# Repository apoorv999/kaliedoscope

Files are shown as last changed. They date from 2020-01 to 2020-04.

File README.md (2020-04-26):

# Kaliedoscope
This project is arduino based Kaliedoscope, developed at CEDT, NSUT. It comprises of two layers of boards. Top layer contains 4 RGB LEDs, switch, USB port for charging and connector for lipo battery. The  lower layer consists of Arduino nano, tilt sensors and power on LED. In this repository you can find the schematic and board files of these layers of boards and also the code for arduino (.ino) for this project.
## Images
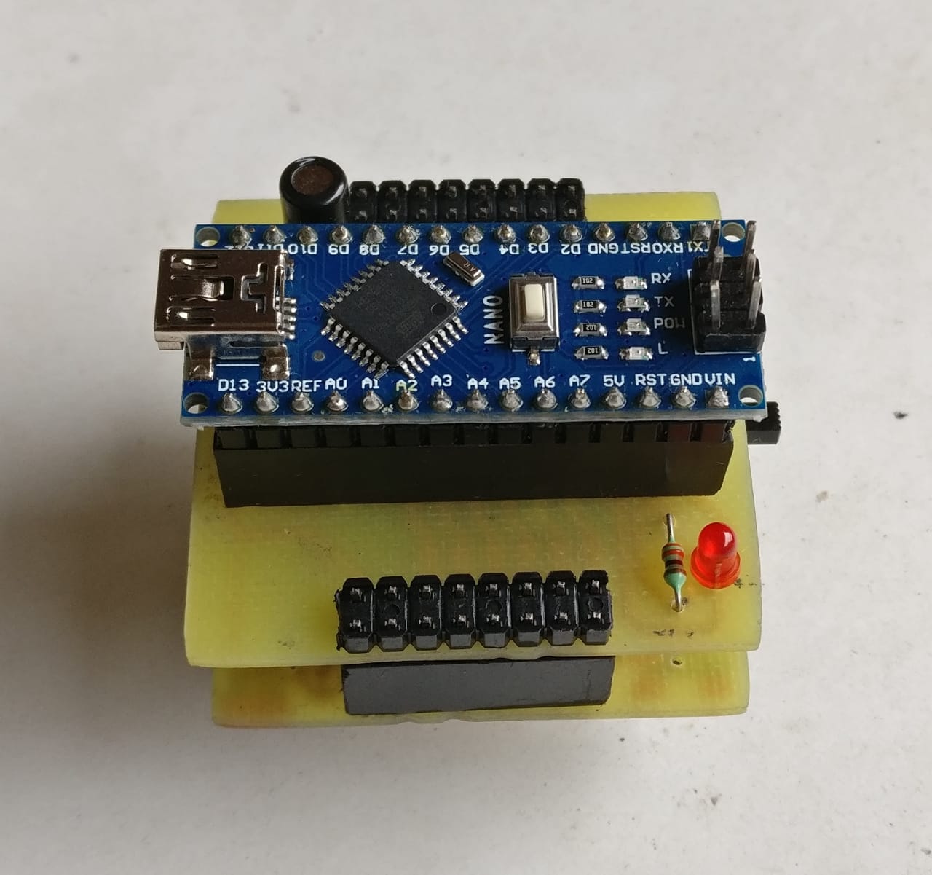
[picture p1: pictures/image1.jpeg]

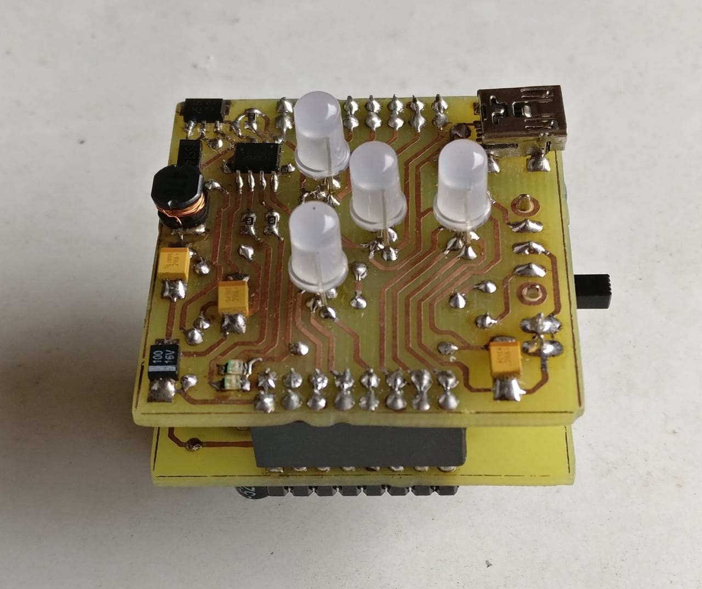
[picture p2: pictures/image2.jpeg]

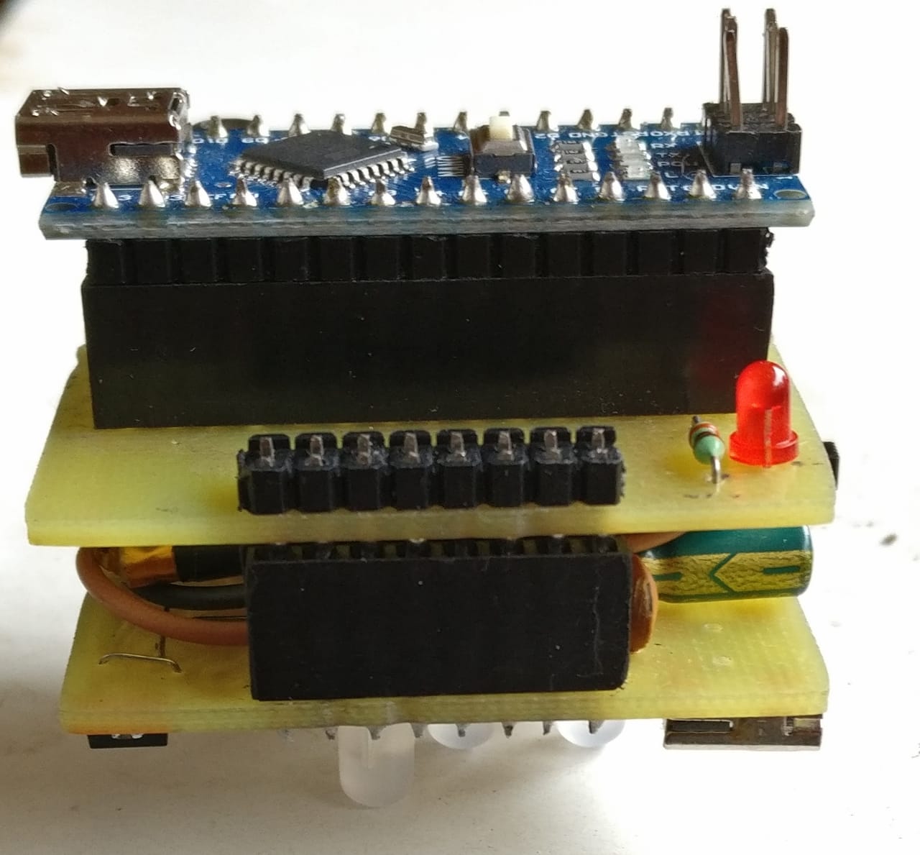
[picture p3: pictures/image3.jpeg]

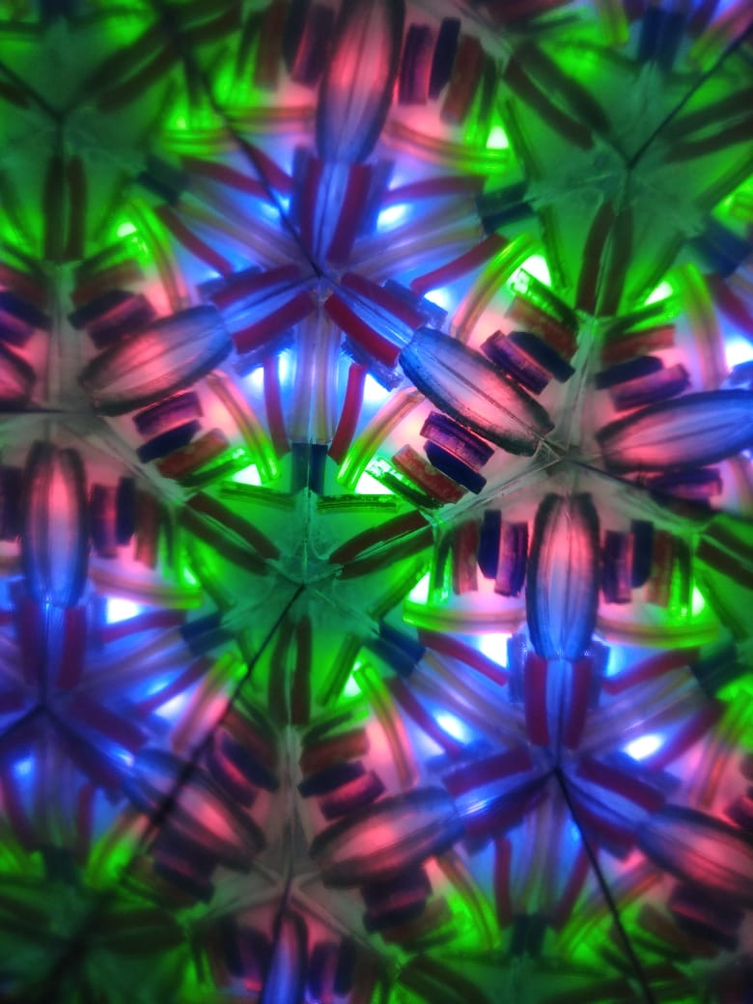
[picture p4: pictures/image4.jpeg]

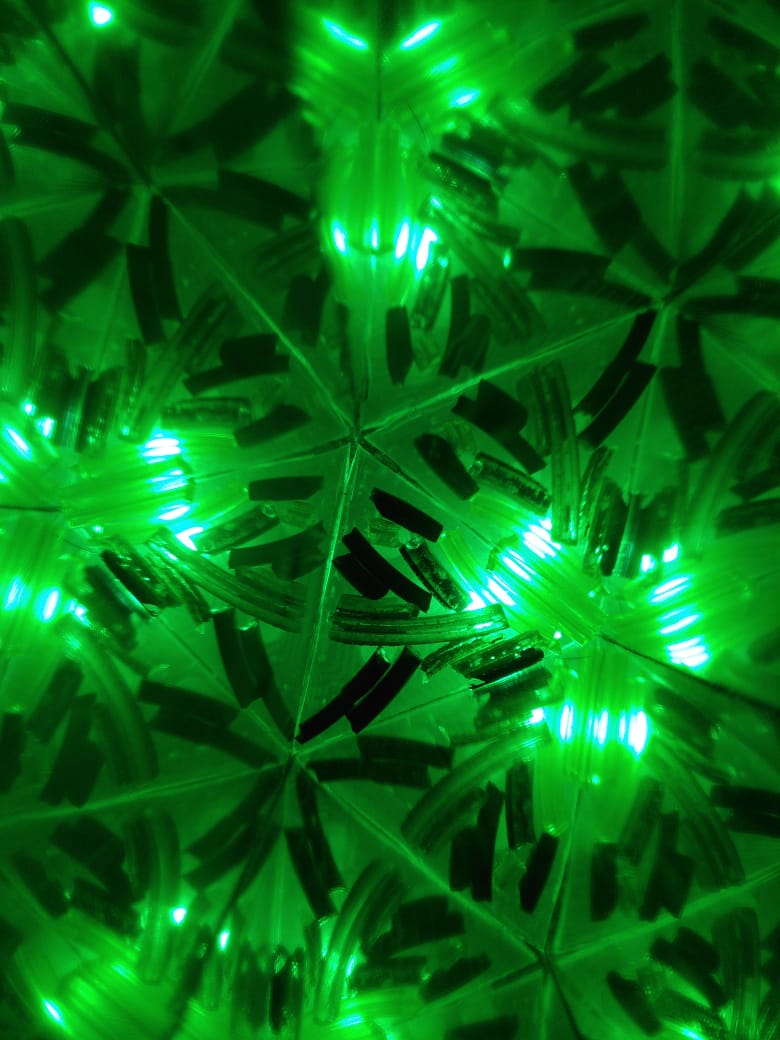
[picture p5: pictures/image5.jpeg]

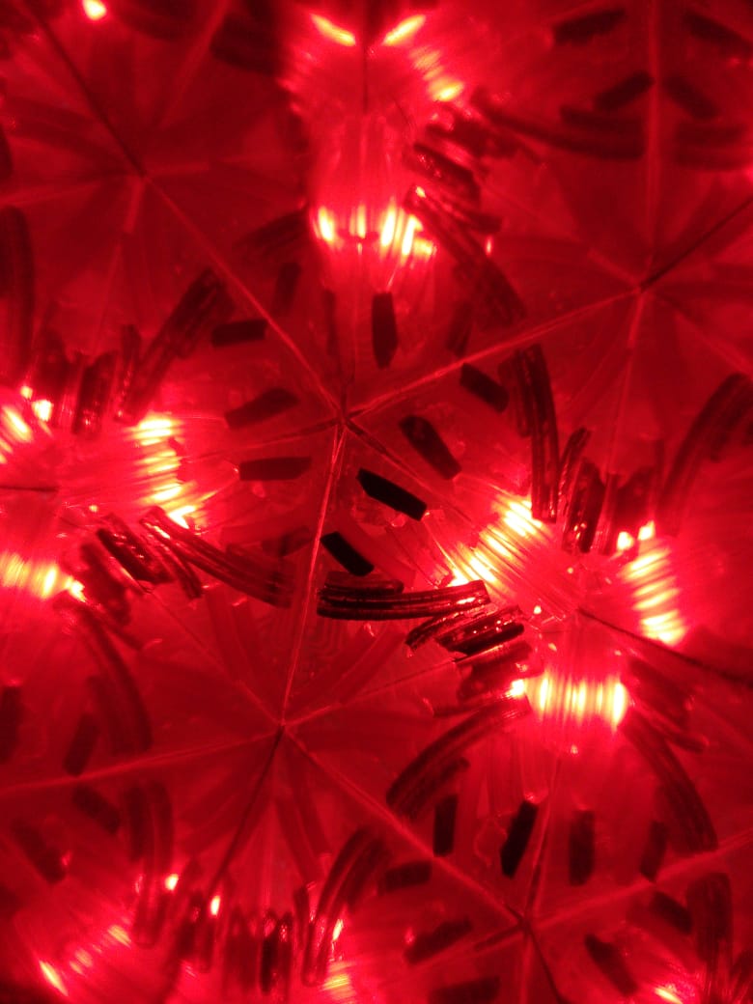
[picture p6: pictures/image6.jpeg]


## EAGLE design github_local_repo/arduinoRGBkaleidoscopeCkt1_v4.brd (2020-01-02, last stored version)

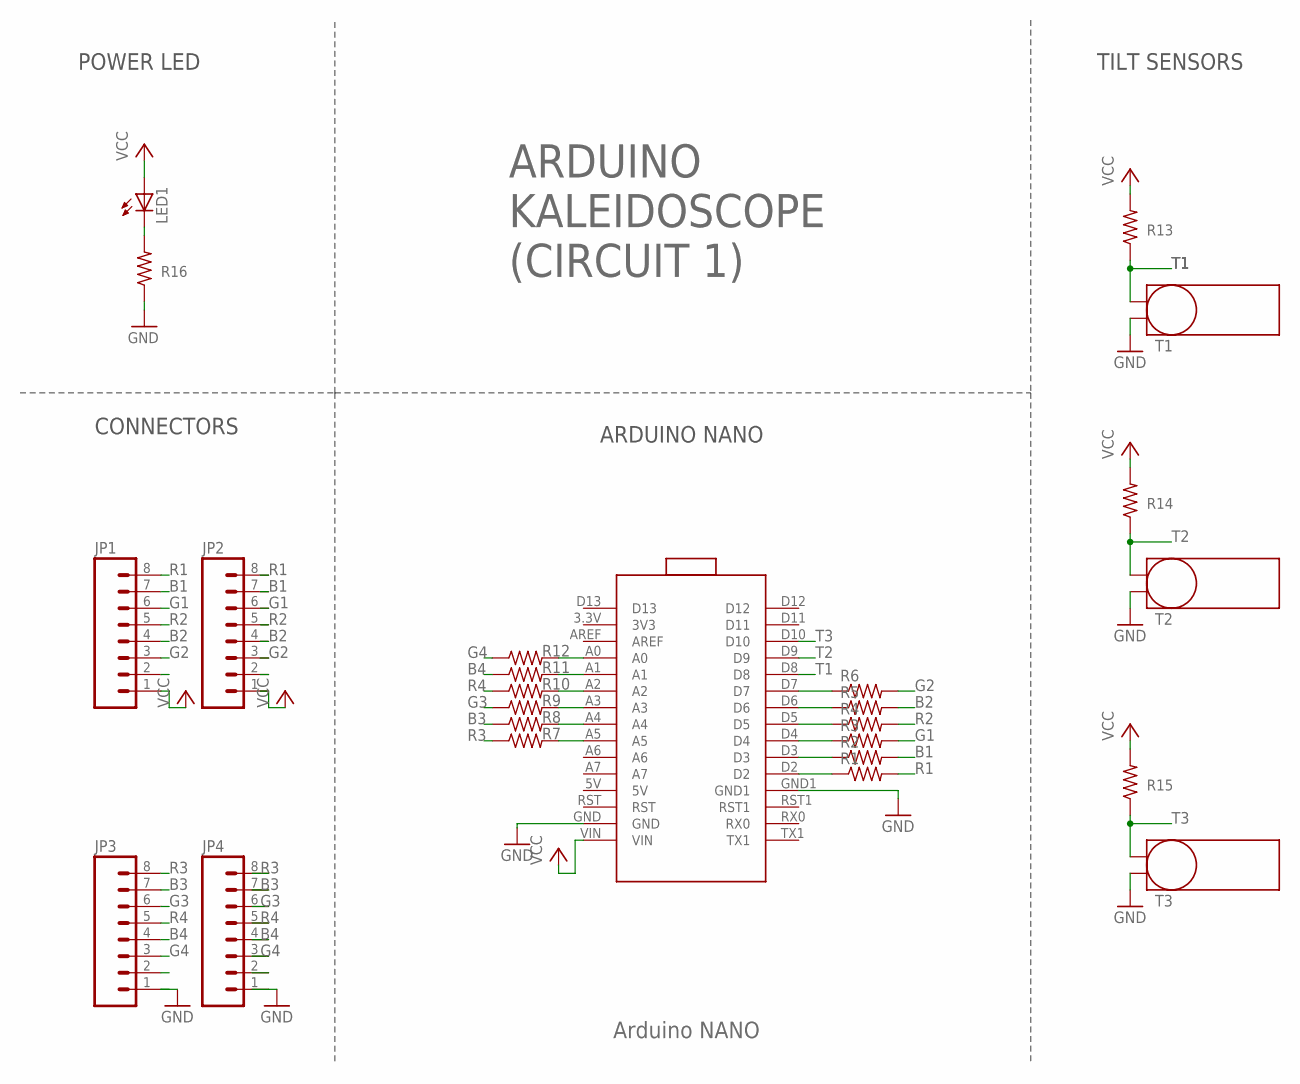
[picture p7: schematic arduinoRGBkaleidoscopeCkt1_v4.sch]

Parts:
JP1, JP2, JP3, JP4: M081X08; 1X08
LED1: LED3MM
R1, R2, R3, R4, R5, R6, R7, R8, R9, R10, R11, R12: RESISTOR0805; R0805
R13, R14, R15, R16: R-US_0204/7; 0204/7
T1, T2, T3: TILTSENSORE2.5-7; TILTSENSOR
U$2: NANO; NANO-2

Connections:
B1: JP1.7, JP2.7, R2.2
B2: JP1.4, JP2.4, R5.2
B3: JP3.7, JP4.7, R8.1
B4: JP3.4, JP4.4, R11.1
G1: JP1.6, JP2.6, R3.2
G2: JP1.3, JP2.3, R6.2
G3: JP3.6, JP4.6, R9.1
G4: JP3.3, JP4.3, R12.1
GND: JP3.1, JP4.1, R16.1, T1.-, T2.-, T3.-, U$2.GND, U$2.GND1
unnamed: R12.2, U$2.A0
unnamed: R11.2, U$2.A1
unnamed: R10.2, U$2.A2
unnamed: R9.2, U$2.A3
unnamed: R8.2, U$2.A4
unnamed: R7.2, U$2.A5
unnamed: R6.1, U$2.D7
unnamed: R5.1, U$2.D6
unnamed: R4.1, U$2.D5
unnamed: R3.1, U$2.D4
unnamed: R2.1, U$2.D3
unnamed: R1.1, U$2.D2
unnamed: LED1.K (C), R16.2
R1: JP1.8, JP2.8, R1.2
R2: JP1.5, JP2.5, R4.2
R3: JP3.8, JP4.8, R7.1
R4: JP3.5, JP4.5, R10.1
T1: R13.1, T1.+, U$2.D8
T2: R14.1, T2.+, U$2.D9
T3: R15.1, T3.+, U$2.D10
VCC: JP1.1, JP2.1, LED1.A, R13.2, R14.2, R15.2, U$2.VIN

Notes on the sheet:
Arduino NANO
POWER LED
TILT SENSORS
ARDUINO NANO
CONNECTORS
ARDUINO KALEIDOSCOPE (CIRCUIT 1)

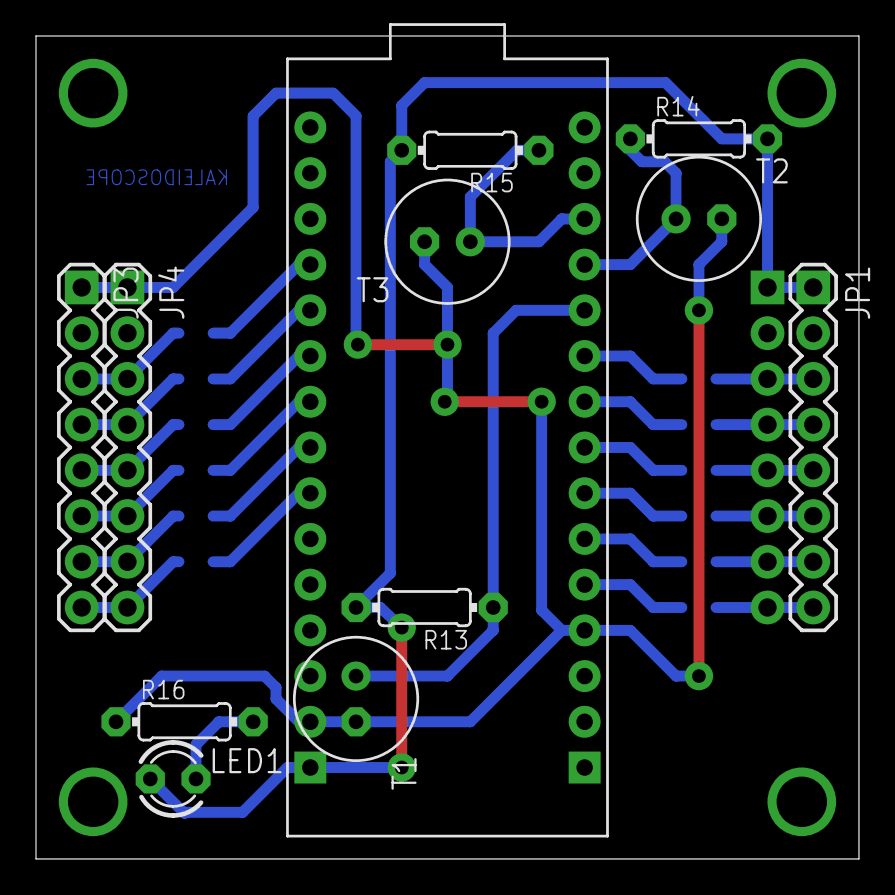
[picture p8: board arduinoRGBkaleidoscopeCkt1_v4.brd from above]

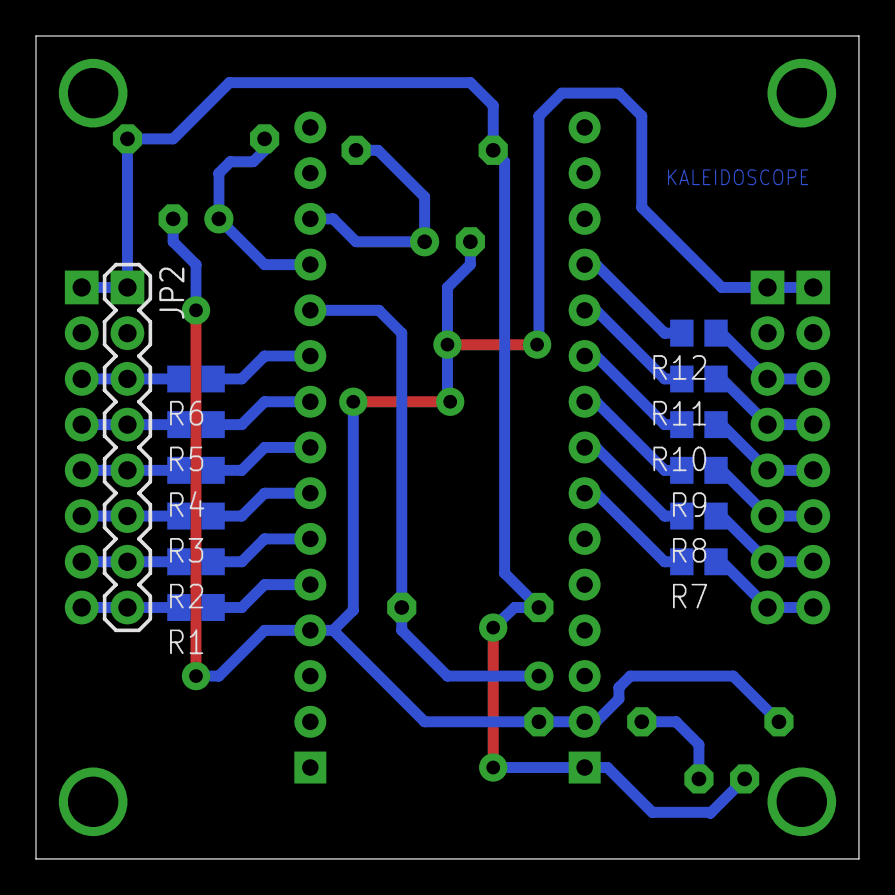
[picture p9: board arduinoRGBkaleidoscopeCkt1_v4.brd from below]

Board: 2 copper layers, 45.7 x 45.7 mm, 25 parts (13 on the bottom side), 30 nets.

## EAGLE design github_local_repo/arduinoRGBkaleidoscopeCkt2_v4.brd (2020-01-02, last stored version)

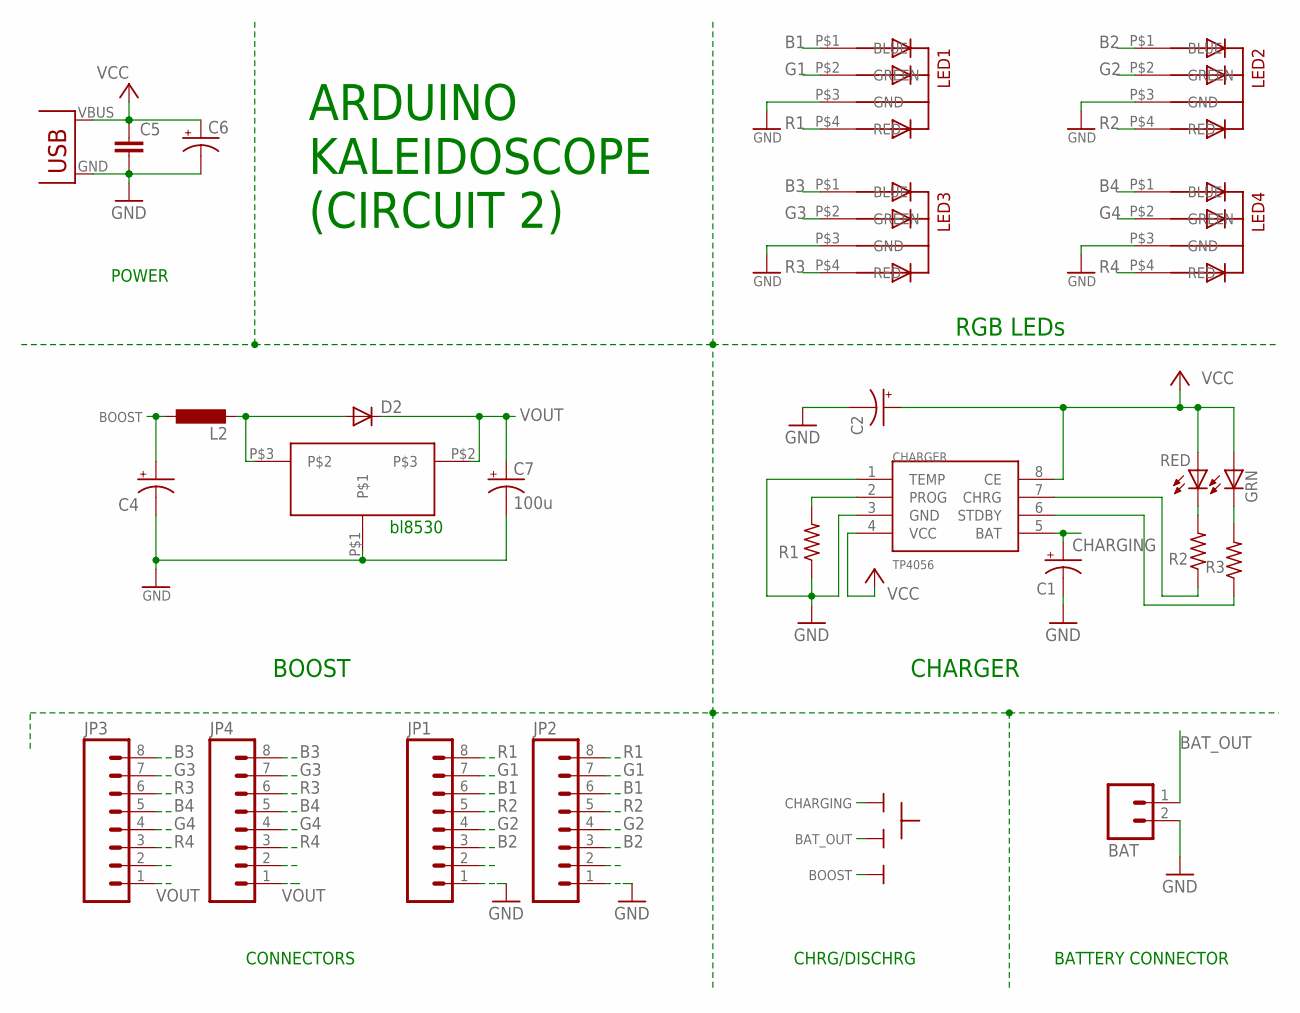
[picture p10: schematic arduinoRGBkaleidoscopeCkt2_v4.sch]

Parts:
BAT: M02; 02P
BOOST: BL8530_5V
C1, C2, C4: 10u; C/6032-28R
C5: C-EU025-024X044; C025-024X044
C6: CPOL-USE2,5-6E; E2,5-6E
C7: 100u; C/6032-28R
CHARGER: TP4056; SOP-8
CHRG/DISCHRG: SLIDESWITCH-BIG; BIGSWITCH
D2: DIODE-DO214AA; DO214AA
GRN: LED3MM; CHIPLED_0805
JP1, JP2, JP3, JP4: M081X08; 1X08
L2: 47uH; L4532P
LED1, LED2, LED3, LED4: 5MMRGBLED; LED5MMRGB
R1: RESISTOR0805; R0805
R2, R3: 470; R0805
RED: LED3MM; CHIPLED_0805
U$1: USB(POWER)

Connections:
B1: JP1.6, JP2.6, LED1.P$1 (BLUE)
B2: JP1.3, JP2.3, LED2.P$1 (BLUE)
B3: JP3.8, JP4.8, LED3.P$1 (BLUE)
B4: JP3.5, JP4.5, LED4.P$1 (BLUE)
BAT_OUT: BAT.1, CHRG/DISCHRG.2
BOOST: C4.+, CHRG/DISCHRG.3, L2.1
CHARGING: C1.+, CHARGER.5 (BAT), CHRG/DISCHRG.1
G1: JP1.7, JP2.7, LED1.P$2 (GREEN)
G2: JP1.4, JP2.4, LED2.P$2 (GREEN)
G3: JP3.7, JP4.7, LED3.P$2 (GREEN)
G4: JP3.4, JP4.4, LED4.P$2 (GREEN)
GND: BAT.2, BOOST.P$1, C1.-, C2.-, C4.-, C5.2, C6.-, C7.-, CHARGER.1 (TEMP), CHARGER.3 (GND), JP1.1, JP2.1, LED1.P$3 (GND), LED2.P$3 (GND), LED3.P$3 (GND), LED4.P$3 (GND), R1.1, U$1.GND
unnamed: CHARGER.2 (PROG), R1.2
unnamed: R2.2, RED.C
unnamed: CHARGER.7 (CHRG), R2.1
unnamed: CHARGER.6 (STDBY), R3.1
unnamed: BOOST.P$3, D2.A, L2.2
unnamed: GRN.C, R3.2
R1: JP1.8, JP2.8, LED1.P$4 (RED)
R2: JP1.5, JP2.5, LED2.P$4 (RED)
R3: JP3.6, JP4.6, LED3.P$4 (RED)
R4: JP3.3, JP4.3, LED4.P$4 (RED)
VCC: C2.+, C5.1, C6.+, CHARGER.4 (VCC), CHARGER.8 (CE), GRN.A, RED.A, U$1.VBUS (VCC)
VOUT: BOOST.P$2, C7.+, D2.C, JP3.1, JP4.1

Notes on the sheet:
BOOST
bl8530
CHARGER
RGB LEDs
POWER
BATTERY CONNECTOR
CONNECTORS
ARDUINO KALEIDOSCOPE (CIRCUIT 2)

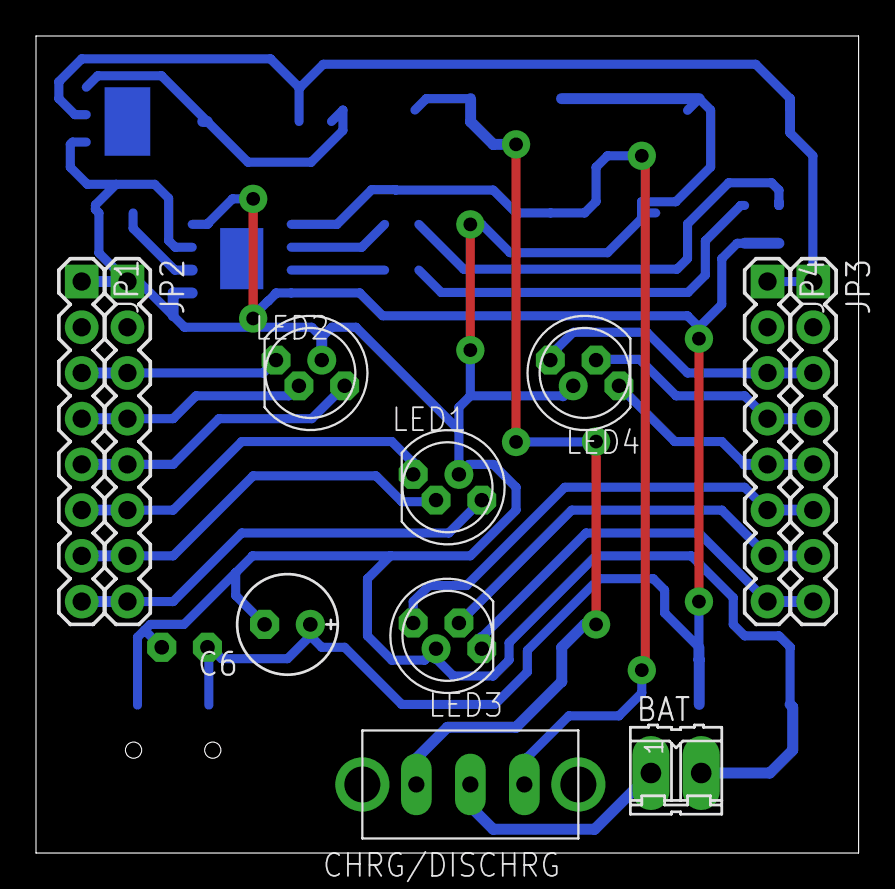
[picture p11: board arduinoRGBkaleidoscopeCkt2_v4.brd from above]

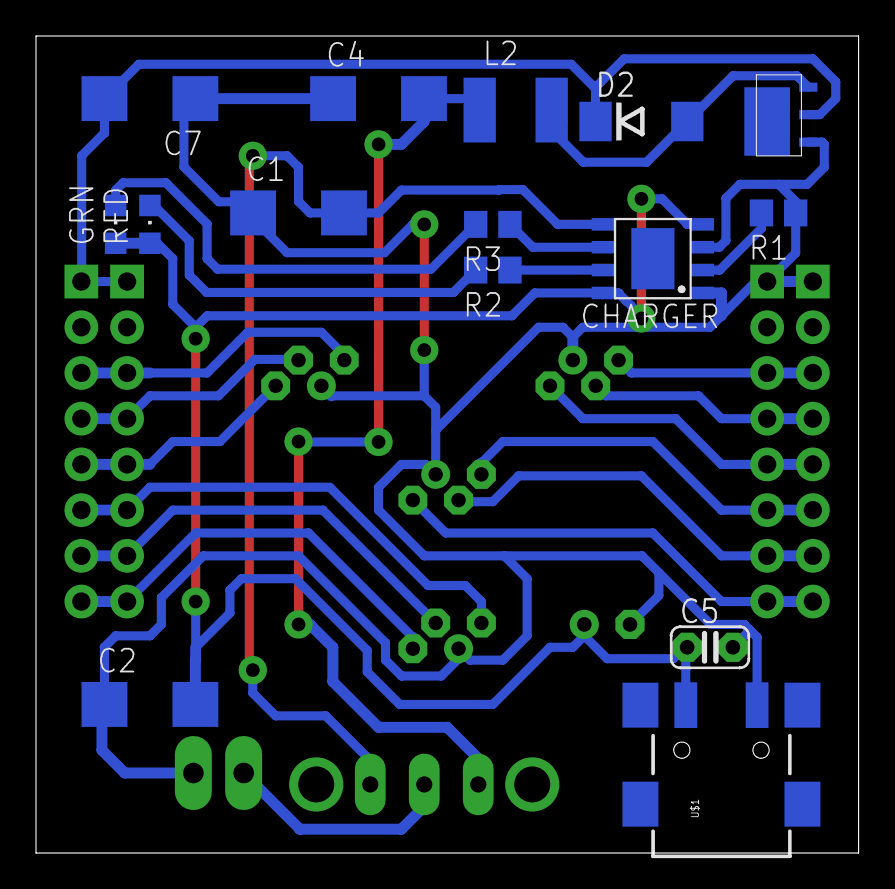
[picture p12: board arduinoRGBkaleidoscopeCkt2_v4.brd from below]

Board: 2 copper layers, 45.7 x 45.4 mm, 26 parts (15 on the bottom side), 24 nets.

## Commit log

2020-01-02 my first commit
    [ArduiKaleiMainCkt1_v2.brd, ArduiKaleiMainCkt1_v2.sch, ArduiKaleiMainCkt2_v2.brd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]
2020-01-02 updated eagle files
    [arduinoRGBkaleidoscopeCkt1_v4.brd, arduinoRGBkaleidoscopeCkt1_v4.sch, arduinoRGBkaleidoscopeCkt2_v4.brd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]
2020-04-26 All files updated
    [ArduiKaleiMainCkt1_v2.brd, ArduiKaleiMainCkt1_v2.sch, ArduiKaleiMainCkt2_v2.brd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]

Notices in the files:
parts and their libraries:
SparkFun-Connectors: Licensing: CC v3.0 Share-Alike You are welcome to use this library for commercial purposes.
